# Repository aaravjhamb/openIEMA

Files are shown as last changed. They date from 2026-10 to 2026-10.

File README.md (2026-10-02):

<h1 align="center">OpenIEMA</h1>
<div align="center">

**OpenIEMA** is an Open Source, In Ear Monitor Amplifier built as an alternative to the Behringer P2 with dual headphone outputs driven from a mono balanced XLR input, with onboard LiPo power and USB-C charging!!







</div>

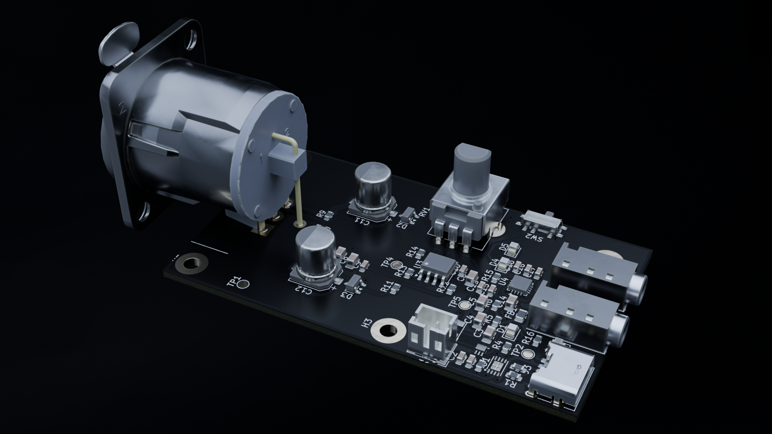
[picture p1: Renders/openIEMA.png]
Hero Render


## Key Features

| | |
|---|---|
| **True balanced input** | Neutrik XLR into an OPA1678 differential line receiver which ensures any long cable runs from the mixer stay noise free |
| **Dual 3.5mm outputs** | supports up to two IEM users off one beltpack, driven by a TI TPA6132A2 DirectPath amp! |
| **Analog soft limiter** | anti parallel LEDs act as soft limiters that clamp excess noise before you hear it! |
| **Fully portable** | Uses a 1S LiPo with USB C charging (MCP73831, 500 mA) and a boost converter to a clean 5 V analog rail, charges while switched off |
| **Zero firmware** | 100% analog signal path built for simplicity |
| **3D-printed enclosure** | Includes a 3D printed enclosure with volume control all in a compact package! |

## PCB

40 × 70 mm, 2-layer, designed in KiCad 10.

**Schematic:**

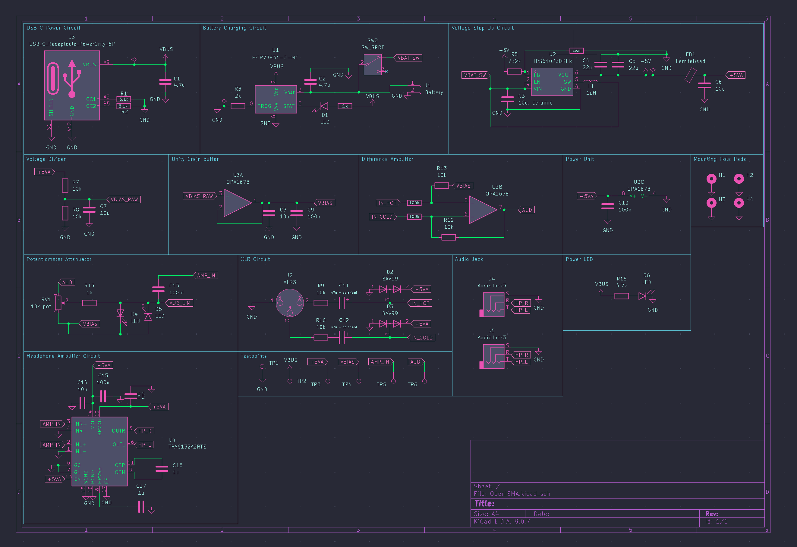
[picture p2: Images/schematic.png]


**Layout:**

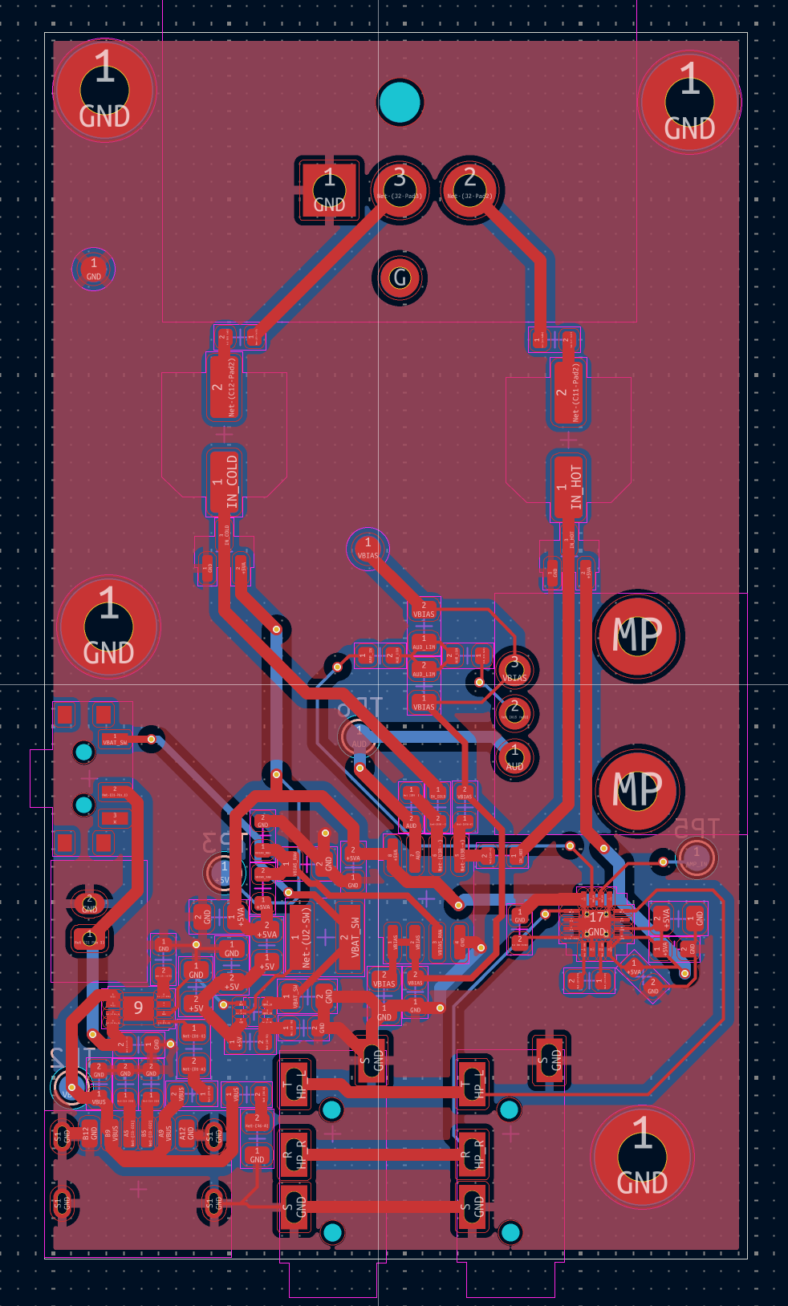
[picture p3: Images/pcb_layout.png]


**3D View:**

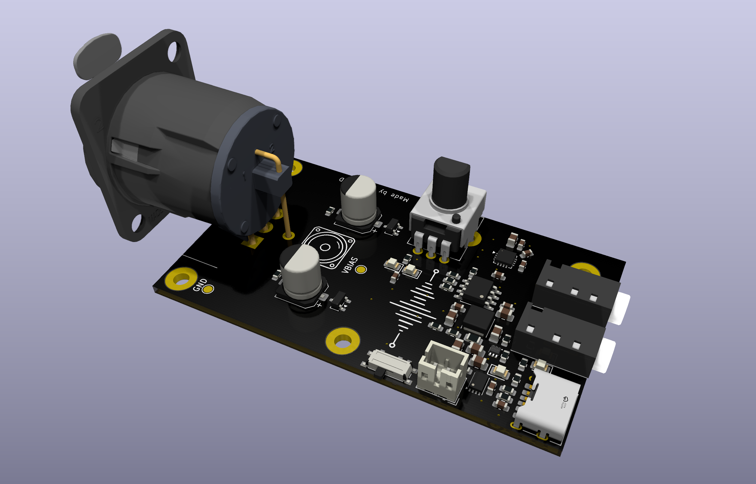
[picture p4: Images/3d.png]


## Case

Designed in Fusion 360

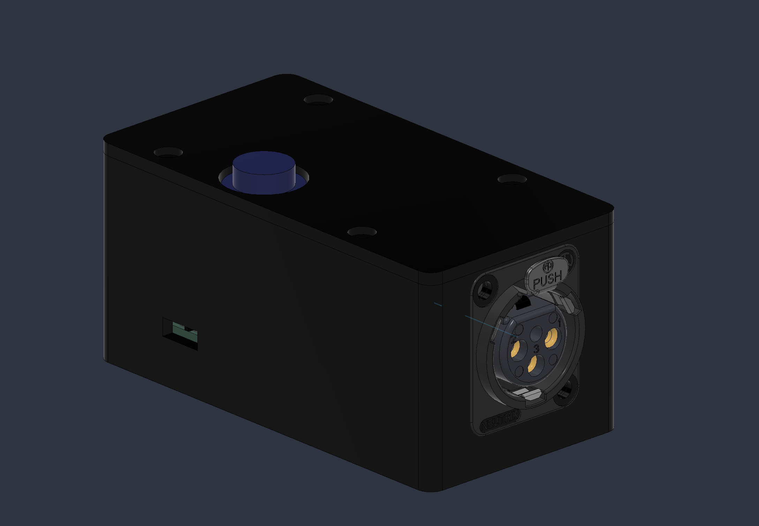
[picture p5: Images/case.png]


## Credits

This project uses:

- [KiCad 10](https://www.kicad.org/) for schematic capture and layout
- [pcb2blender](https://github.com/30350n/pcb2blender) for the Blender renders
- TI TPA6132A2 + OPA1678, Microchip MCP73831, TI TPS61023

## License

MIT

---

> [aaravj.tech]() · GitHub [@aaravjhamb](https://github.com/aaravjhamb/)

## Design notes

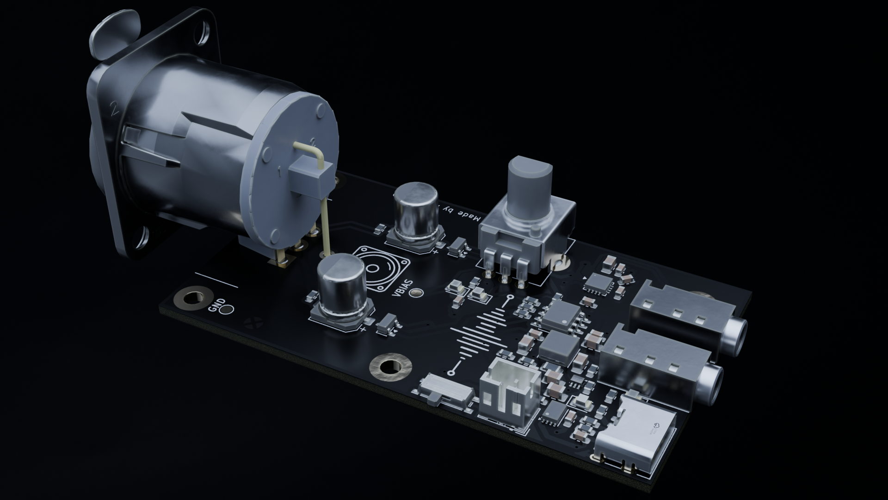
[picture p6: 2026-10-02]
Images/openIEMA.png

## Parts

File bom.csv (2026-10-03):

Designator | Qty | Value / Part | Description | Footprint / Package | LCSC Part # | Source | Cost (AUD)
C1, C2 | 2 | 4.7u |  | 0603 |  | JLCPCB
C10, C15, C16, C9 | 4 | 100n |  | 0603 |  | JLCPCB
C11, C12 | 2 | 47u - polarized |  | CP_Elec_6.3x7.7 |  | JLCPCB
C13 | 1 | 100nf |  | 0603 |  | JLCPCB
C14, C6, C7, C8 | 4 | 10u |  | 0805 |  | JLCPCB
C17, C18 | 2 | 1u |  | 0603 |  | JLCPCB
C3 | 1 | 10u, ceramic |  | 0805 |  | JLCPCB
C4, C5 | 2 | 22u |  | 0805 |  | JLCPCB
D1, D4, D5, D6 | 4 | LED |  | 0805 |  | JLCPCB
D2, D3 | 2 | BAV99 |  | SOT-23 |  | JLCPCB
FB1 | 1 | FerriteBead |  | 0805 |  | JLCPCB
J1 | 1 | Battery |  | JST_PH_B2B-PH-K_1x02_P2.00mm_Vertical |  | JLCPCB
J2 | 1 | XLR3 |  | Jack_XLR_Neutrik_NC3FD-H_Horizontal |  | JLCPCB
J3 | 1 | USB_C_Receptacle_PowerOnly_6P |  | USB_C_Receptacle_HRO_TYPE-C-31-M-17 |  | JLCPCB
J4, J5 | 2 | AudioJack3 |  | Jack_3.5mm_PJ320A_Horizontal | C12569 | JLCPCB
L1 | 1 | 1uH |  | L_Taiyo-Yuden_NR-40xx |  | JLCPCB
R1, R2 | 2 | 5.1k |  | 0603 |  | JLCPCB
R10, R12, R13, R7, R8, R9 | 6 | 10k |  | 0603 |  | JLCPCB
R11, R14, R6 | 3 | 100k |  | 0603 |  | JLCPCB
R15, R4 | 2 | 1k |  | 0603 |  | JLCPCB
R16 | 1 | 4.7k |  | 0603 |  | JLCPCB
R3 | 1 | 2k |  | 0603 |  | JLCPCB
R5 | 1 | 732k |  | 0603 |  | JLCPCB
RV1 | 1 | 10k pot |  | Potentiometer_Bourns_PTV09A_Single_Vertical |  | JLCPCB
SW2 | 1 | SW_SPDT |  | SW_SPDT_PCM12 |  | JLCPCB
TP1, TP2, TP3, TP4, TP5, TP6 | 6 | TestPoint |  | TestPoint_Pad_D1.5mm |  | JLCPCB
U1 | 1 | MCP73831-2-MC |  | DFN-8-1EP_3x2mm_P0.5mm_EP1.7x1.4mm |  | JLCPCB
U2 | 1 | TPS61023DRLR |  | SOT-563_L1.6-W1.2-P0.50-LS1.6-BR | C919459 | JLCPCB
U3 | 1 | OPA1678 |  | SOIC-8_3.9x4.9mm_P1.27mm |  | JLCPCB
U4 | 1 | TPA6132A2RTE |  | WQFN-16-1EP_3x3mm_P0.5mm_EP1.6x1.6mm_ThermalVias |  | JLCPCB
 | 1 | Silk PLA | Case |  |  | Jaycar | $19
 | 1 | IEM | In ear monitors for testing |  |  | https://www.amazon.com.au/KS1-Headphones-Resolution-Detachable-Black-Nomic/dp/B08TWQ3TR7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 | $25
 | 1 | Polymer Lithium Ion Battery (LiPo) 3.7V 1100mAh | Battery |  |  | https://core-electronics.com.au/polymer-lithium-ion-battery-1000mah-38458.html | $9
 |  |  |  |  |  | Non-PCB subtotal | $53

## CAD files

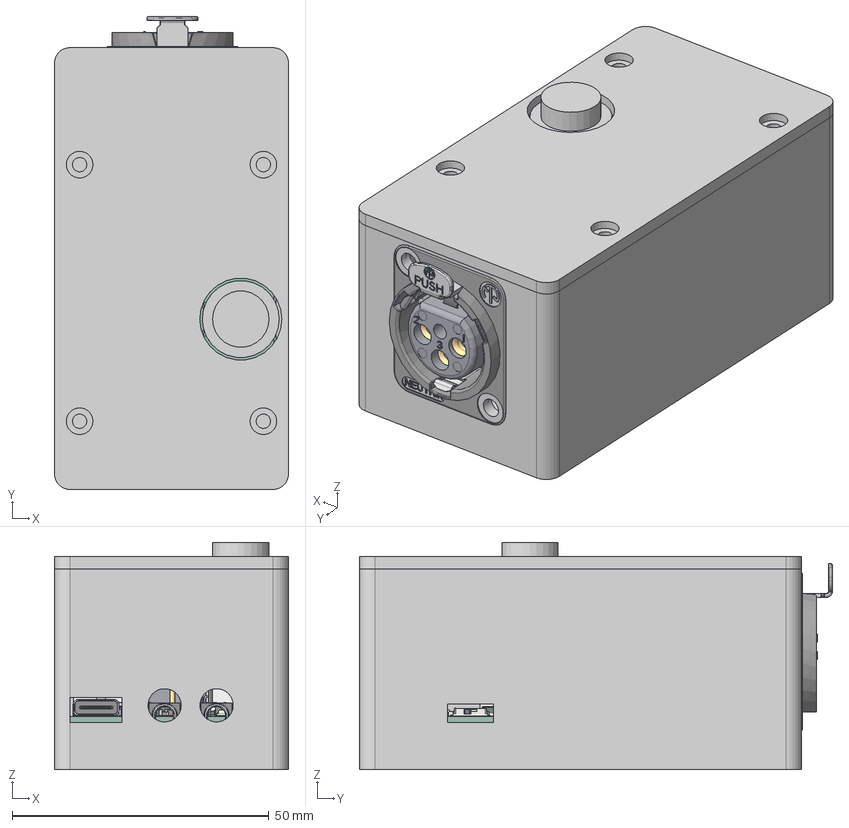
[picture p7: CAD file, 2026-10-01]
CAD/STEPS/OpenIEMA Assembly.step
45.6 x 92.2 x 44.3 mm
C_0603_1608Metric x 9
Potentiometer_Bourns_PTV09A_Single_Vertical
C_0805_2012Metric x 7
LED_0805_2012Metric x 4
AUDIO-TH_PJ-320A x 2
CP_Elec_6.3x7.7 x 2
SOT-23 x 2
JST_PH_B2B-PH-K_1x02_P2.00mm_Vertical
DFN-8-1EP_3x2mm_P0.5mm_EP1.75x1.45mm
SOIC-8_3.9x4.9mm_P1.27mm
R_0603_1608Metric x 16
SOT-563-6P_L1.6-W1.2-H0.6-LS1.6-P0.50
WQFN-16-1EP_3x3mm_P0.5mm_EP1.6x1.6mm
SW_SPDT_PCM12
USB_C_Receptacle_HRO_TYPE-C-31-M-17
L_APV_ANR4018
R_0805_2012Metric
OpenIEMA_PCB
OpenIEMA Case

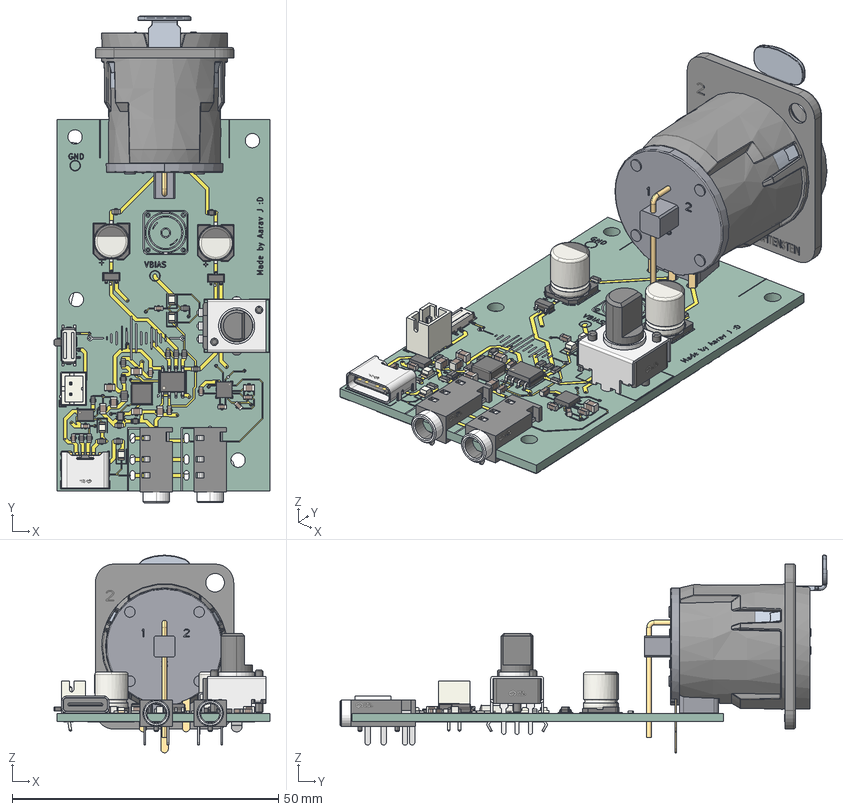
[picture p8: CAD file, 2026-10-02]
CAD/STEPS/OpenIEMA.step
40.6 x 91.4 x 37.1 mm
C_0603_1608Metric x 9
Potentiometer_Bourns_PTV09A_Single_Vertical
C_0805_2012Metric x 7
LED_0805_2012Metric x 4
AUDIO-TH_PJ-320A x 2
CP_Elec_6.3x7.7 x 2
SOT-23 x 2
JST_PH_B2B-PH-K_1x02_P2.00mm_Vertical
DFN-8-1EP_3x2mm_P0.5mm_EP1.75x1.45mm
SOIC-8_3.9x4.9mm_P1.27mm
R_0603_1608Metric x 16
SOT-563-6P_L1.6-W1.2-H0.6-LS1.6-P0.50
WQFN-16-1EP_3x3mm_P0.5mm_EP1.6x1.6mm
SW_SPDT_PCM12
USB_C_Receptacle_HRO_TYPE-C-31-M-17
L_APV_ANR4018
R_0805_2012Metric
OpenIEMA_copper
OpenIEMA_via
OpenIEMA_silkscreen x 2
OpenIEMA_PCB

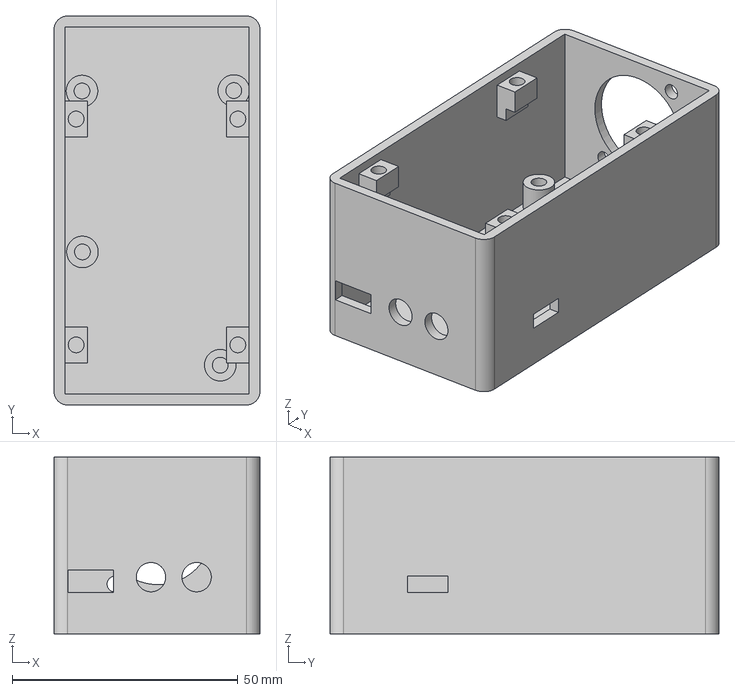
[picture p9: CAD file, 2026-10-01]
CAD/STEPS/Base.step
45.6 x 86.1 x 39.1 mm

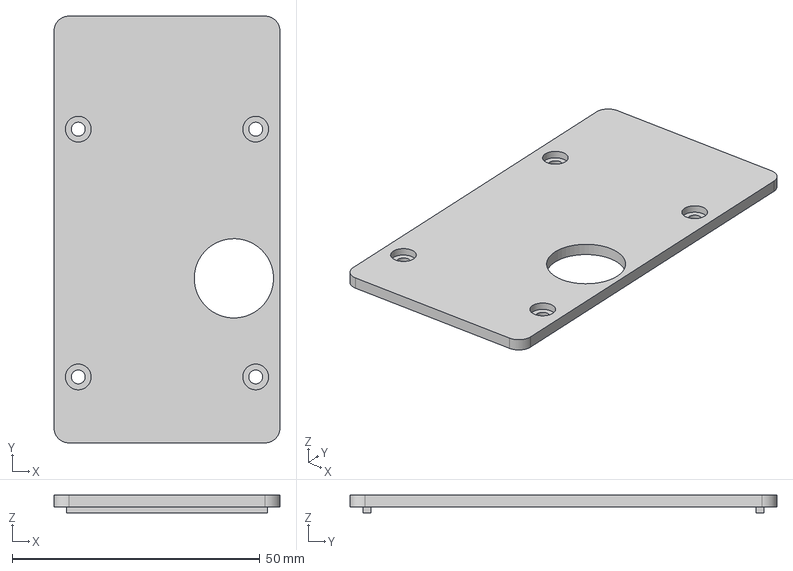
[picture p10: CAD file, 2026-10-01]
CAD/STEPS/Lid.step
45.6 x 86.1 x 3.60 mm

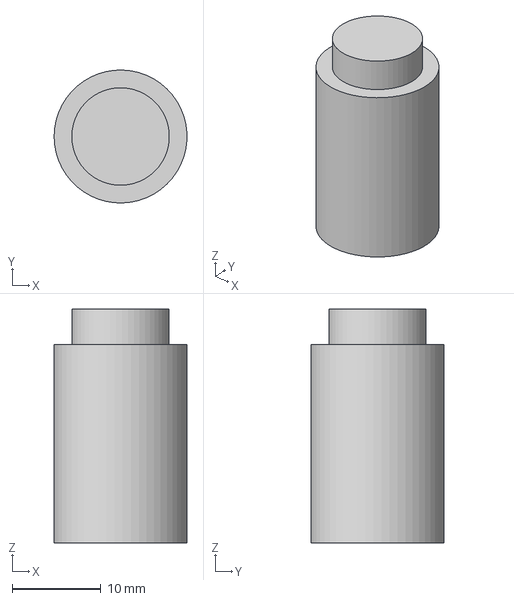
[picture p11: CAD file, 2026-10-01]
CAD/STEPS/Knob.step
15.0 x 15.0 x 26.4 mm

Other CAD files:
CAD/3D Printing/Base.stl
CAD/3D Printing/Knob.stl
CAD/3D Printing/Lid.stl
Renders/openIEMA.blend

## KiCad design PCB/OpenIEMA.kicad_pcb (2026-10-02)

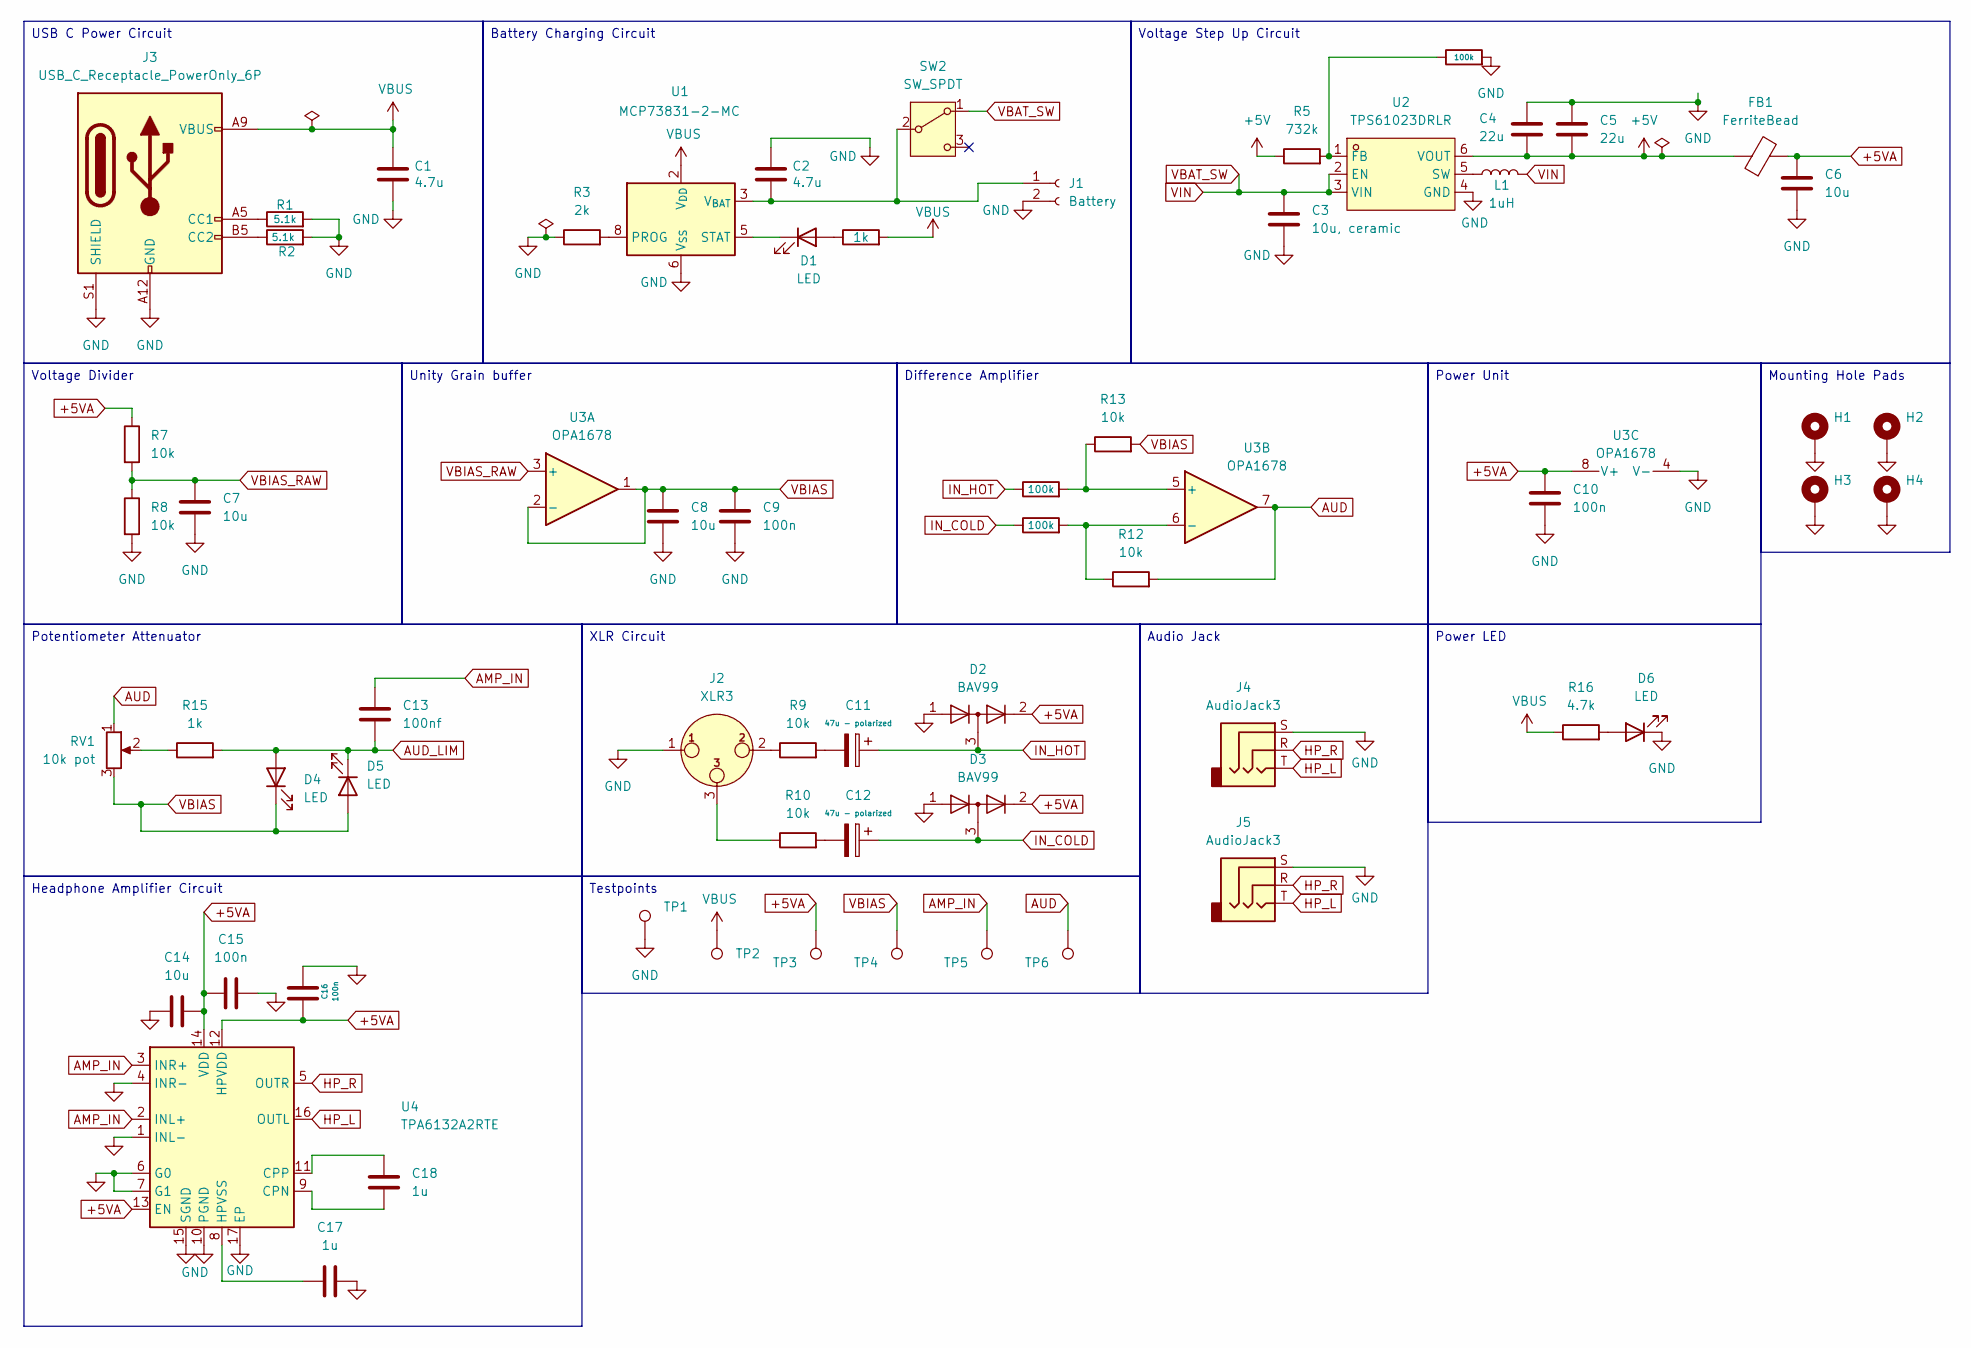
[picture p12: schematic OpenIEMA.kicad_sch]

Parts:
C1, C2: 4.7u; C_0603_1608Metric
C3: 10u, ceramic; C_0805_2012Metric
C4, C5: 22u; C_0805_2012Metric
C6, C7, C8, C14: 10u; C_0805_2012Metric
C9, C10, C15, C16: 100n; C_0603_1608Metric
C11, C12: 47u - polarized; CP_Elec_6.3x7.7
C13: 100nf; C_0603_1608Metric
C17, C18: 1u; C_0603_1608Metric
D1, D4, D5, D6: LED; LED_0805_2012Metric
D2, D3: BAV99; SOT-23
FB1: FerriteBead; R_0805_2012Metric
H1, H2, H3, H4: MountingHole_Pad; MountingHole_2.7mm_M2.5_Pad
J1: Battery; JST_PH_B2B-PH-K_1x02_P2.00mm_Vertical
J2: XLR3; Jack_XLR_Neutrik_NC3FD-H_Horizontal
J3: USB_C_Receptacle_PowerOnly_6P; USB_C_Receptacle_HRO_TYPE-C-31-M-17
J4, J5: AudioJack3; Jack_3.5mm_PJ320A_Horizontal
L1: 1uH; L_Taiyo-Yuden_NR-40xx
R1, R2: 5.1k; R_0603_1608Metric
R3: 2k; R_0603_1608Metric
R4, R15: 1k; R_0603_1608Metric
R5: 732k; R_0603_1608Metric
R6, R11, R14: 100k; R_0603_1608Metric
R7, R8, R9, R10, R12, R13: 10k; R_0603_1608Metric
R16: 4.7k; R_0603_1608Metric
RV1: 10k pot; Potentiometer_Bourns_PTV09A_Single_Vertical
SW2: SW_SPDT; SW_SPDT_PCM12
TP1, TP2, TP3, TP4, TP5, TP6: TestPoint; TestPoint_Pad_D1.5mm
U1: MCP73831-2-MC; DFN-8-1EP_3x2mm_P0.5mm_EP1.7x1.4mm
U2: TPS61023DRLR; SOT-563_L1.6-W1.2-P0.50-LS1.6-BR; MPN TPS61023DRLR; LCSC Part C919459
U3: OPA1678; SOIC-8_3.9x4.9mm_P1.27mm
U4: TPA6132A2RTE; WQFN-16-1EP_3x3mm_P0.5mm_EP1.6x1.6mm_ThermalVias

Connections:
+5V: C4.2, C5.2, FB1.1, R5.1, U2.6 (VOUT)
+5VA: C6.1, C10.2, C14.2, C15.1, C16.1, D2.2 (A), D3.2 (A), FB1.2, R7.1, TP3.1, U3.8 (V+), U4.12 (HPVDD), U4.13 (EN), U4.14 (VDD)
AMP_IN: C13.1, TP5.1, U4.2 (INL+), U4.3 (INR+)
AUD: R12.2, RV1.1, TP6.1, U3.7
AUD_LIM: C13.2, D4.2 (A), D5.1 (K), R15.2
GND: C1.2, C2.1, C3.2, C4.1, C5.1, C6.2, C7.2, C8.1, C9.1, C10.1, C14.1, C15.2, C16.2, C17.1, D2.1 (K), D3.1 (K), D6.1 (K), H1.1, H2.1, H3.1, H4.1, J1.2, J2.1, J3.A12 (GND), J3.B12 (GND), J3.S1 (SHIELD), J4.S, J5.S, R1.2, R2.2, R3.1, R6.2, R8.2, TP1.1, U1.6 (V_{SS}), U2.4 (GND), U3.4 (V-), U4.1 (INL-), U4.4 (INR-), U4.6 (G0), U4.7 (G1), U4.10 (PGND), U4.15 (SGND), U4.17 (EP)
HP_L: J4.T, J5.T, U4.16 (OUTL)
HP_R: J4.R, J5.R, U4.5 (OUTR)
IN_COLD: C12.1, D3.3 (K), R11.1
IN_HOT: C11.1, D2.3 (K), R14.1
unnamed: C11.2, R9.2
unnamed: C12.2, R10.2
unnamed: D1.2 (A), R4.1
unnamed: D1.1 (K), U1.5 (STAT)
unnamed: D6.2 (A), R16.2
unnamed: C2.2, J1.1, SW2.2 (B), U1.3 (V_{BAT}), U1.4 (V_{BAT})
unnamed: J2.2, R9.1
unnamed: J2.3, R10.1
unnamed: J3.A5 (CC1), R1.1
unnamed: J3.B5 (CC2), R2.1
unnamed: R15.1, RV1.2
unnamed: R3.2, U1.8 (PROG)
unnamed: R5.2, R6.1, U2.1 (FB)
unnamed: L1.1, U2.5 (SW)
unnamed: R13.1, R14.2, U3.5 (+)
unnamed: R11.2, R12.1, U3.6 (-)
unnamed: C18.2, U4.9 (CPN)
unnamed: C18.1, U4.11 (CPP)
unnamed: C17.2, U4.8 (HPVSS)
VBAT_SW: C3.1, L1.2, SW2.1 (A), U2.2 (EN), U2.3 (VIN)
VBIAS: C8.2, C9.2, D4.1 (K), D5.2 (A), R13.2, RV1.3, TP4.1, U3.1, U3.2 (-)
VBIAS_RAW: C7.1, R7.2, R8.1, U3.3 (+)
VBUS: C1.1, J3.A9 (VBUS), J3.B9 (VBUS), R4.2, R16.1, TP2.1, U1.1 (V_{DD}), U1.2 (V_{DD})

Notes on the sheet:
Potentiometer Attenuator
Testpoints
Mounting Hole Pads
Voltage Step Up Circuit
Voltage Divider
Battery Charging Circuit
Audio Jack
Headphone Amplifier Circuit
Power LED
USB C Power Circuit
Power Unit
Difference Amplifier
Unity Grain buffer
XLR Circuit

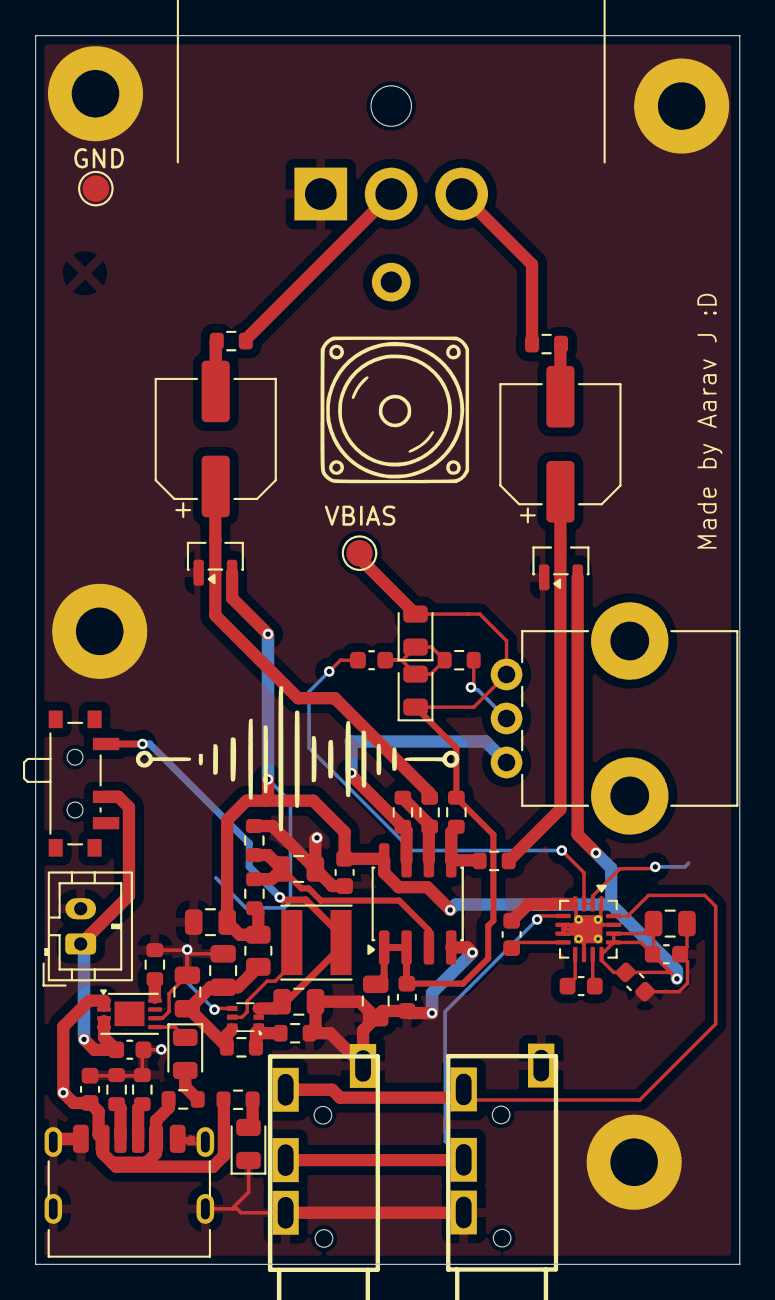
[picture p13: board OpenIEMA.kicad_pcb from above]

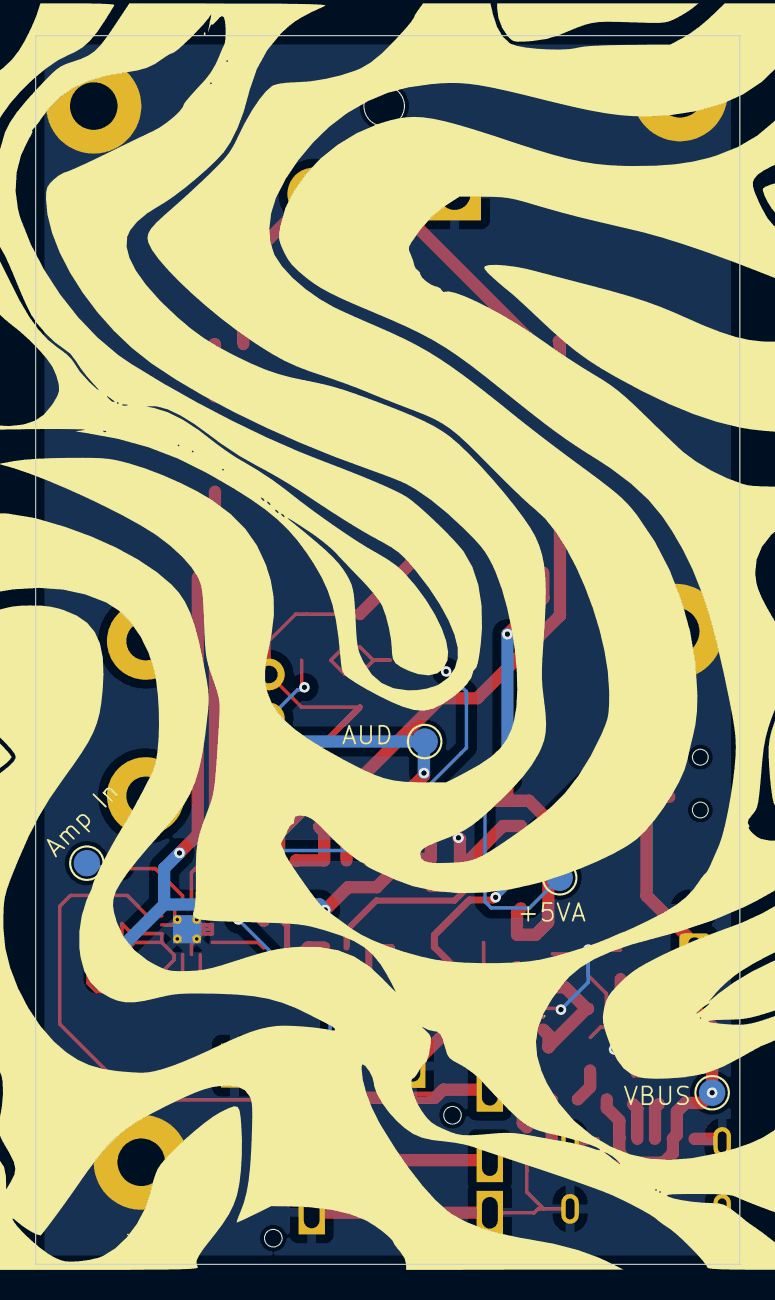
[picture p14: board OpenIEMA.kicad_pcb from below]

Board: 2 copper layers, 40.0 x 69.8 mm, 63 parts (4 on the bottom side), 33 nets.

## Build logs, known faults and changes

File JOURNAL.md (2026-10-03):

---
title: "openIEMA"
author: "Aarav J"
description: "An Open Source, In Ear Monitor Amplifier built as an alternative to the Behringer P2 with dual headphone outputs driven from a mono balanced XLR input, with onboard LiPo power and USB-C charging!!"
created_at: "2026-10-03"
---

# 2026-10-03: Day 7 - (3/10/26) - Github files + JLC quote

**Total time spent: 1.5 hours**

# Day 7

Quick things today, I did this yesterday but I'm devlogging today

I spent a bit of time organising everything into the right folders and it looked like this



I then wrote my github readme and uploaded all the files to GH with some readme polish!

# Time spent : 1.5 hours

With that the entire project is done :DD total time spent was 

# 2026-10-03: Day 6 (2/10/26) - Blender Renders

**Total time spent: 7 hours**

# Day 6

pcb done!! now It was time to make blender renders :D

To do this I first installed the pcb2blender kicad plugin!


This allows me to take my PCB directly from KiCad and import it into blender using the companion extenion in blender. Once I imported it in blender it looked something like this



I then whent to the shading settings and changed the solder mask colour to black and adjusted the strength aswell as changing the surface finish to enig!


once this was done, I whent down to the world icon and set the environment to studio and downloaded this HDRI pack called "wooden_studio_08_4k" that basically handled the lighting and bg for me!



After that I clicked N and opened the view panel to set my camera view

And then locked the object to camera view so I could recenter the PCB with the camera locked!

Once I recentered I whent into view > align > align camera to current view which allows me to set the current view as the camera's view!



Then I clicked Z and 8 to get a test render



Finally once I was happy with this I clicked render and let it render with this being the final result!



All of this took me quite a while with multiple tries as this is my second time using blender and its certainly a difficult software to understand

Time Spent : 7 hours

# 2026-10-03: Day 5 (2/10/26) - Started PCB

**Total time spent: 6 hours**

# Day 5

To make the PCB I first imported all the components from the schematic



Then I did the PCB layout



I tried to place components as close as possible and ensure that routing wouldn't be too crazy so this took ~3 hours with me redoing the board 3 times. I then added the ground pour on both layers and decided to go with a 2 layer board as 4 layers is overkill imo



Then I spent a bit doing routing


And while doing routing I tried to keep the trace widths and lengths as optimized as possible!

I don't have pictures of my rerouting verions however I do have a 3d model of my old PCB vs new layout!

v1 - 


v2 - 


# Time Spent : 6 hours

# 2026-10-03: Day 4 (1/10/26) - Assigning footprints

**Total time spent: 1.5 hours**

# Day 4

Spent a couple hours assigning footprints, there's not much to say lol





# Time spent : 1.5 hours

# 2026-10-03: Day 3 (30/09/26) - Schematic Continuation

**Total time spent: 9 hours**

# Day 3

more journal shennanigans!!! devlogging for two days

first thing I did today was get started on the voltage divider. this is required as the project has a stable +5v supply coming from +5vA however audio works in the negatives aswqell. Our target is to make the waveform clip at 0v however right now 5/2 is 2.5 so I need to create a voltage divider to allow it to swing betweeen -2.5v and +2.5v

This can be achieved simply by using 2 10k resistors like this



After this I need to design the Unity Gain Buffer. This put simply takes 2.5v in from the  voltage divider and turns it from a weak signal to a stronger signal. This can be achieved using the OPA1678 chip which is a 3 part chip.

Part A (the main part) copies the dividers 2.5v to its output and holds it strong and stable so the rest of the circuit can use it and it looks something like this.



The next part (U3B) uses the same chip btu a different symbol and is called the difference amplifier. This basically takes the 2 XLR signals (hot and cold) and subtracts one from the other to remove cable noise and cleanms the audio to about 20db, this is important if I want to get clear sound and looks something like this



The last and final part of the chip is pretty simple, the chip needs some way to power it and to do that I can use U3C which is the power input of the chip!



It's pretty simple and just takes our cleaned 5va, with a decoupling cap to GND and v- going to ground!

That's the hard part done!! Now I can move onto the fun part's - volume control and sound output but before I move on I actually need to design the XLR input circuit! 



This basically takes the XLR input and shoves it through a diode to prevent backflow and gives the two outputs that then input into the difference amplifier!

Now it's time for the audio volume control! I can achieve this using a potentiometer and 2 LED's that clip the signal such as the high peaks that kill your ears



This also provides accurate volume control going out to the HAC (headphone amplifier circuit) chip



Finally to finish off I added the two headphone jacks,

 and some tespoints and power LED's

once all done, it looked something like this!



Now I can move onto the PCB once I assign footprints

# Time spent : 9 hours

# 2026-10-03: Day 1 - Started Schematic

**Total time spent: 5 hours**

# Day 1

guess who forgot to journal!!! anyway I'm setting out to build an open source IEMA or In Ear Monitor Amplifier for short
I want to build this as an alternative to the Bereginer C2 as that is a bit costly and doesn't have some features I want

To get started I'm going to be making this project as a fully analog circuit!! since this is my first time I'm going to have to understand how sound engineering works(fun)

my first step was to add USB C with the usual setup like so



This is just a simple USB C PCB implementation that has 2 5.1k resistors to invoke the USB C power protocol + a power flag so kicad stops yelling at me and a simple decoupling cap placed on vbus for stability!

The next step was to add a battery charging circuit and do some research for the chip + the battery capacity and time I wanted the device to operate. My first thoughts was to use the TP4056 charging module but I wanted to go with something new and easier and more efficient to operate so after consulting my [boss] claude I decided to go with the MCP73831-2-MC chip. 

I then whent throughout the [datasheet](https://ww1.microchip.com/downloads/en/DeviceDoc/MCP73831-Family-Data-Sheet-DS20001984H.pdf) and tried to find an example circuit that looked somethinig like this



I imported it into kicad and made a circuit that looked something similar to this



This circuit is pretty simple and in essence here's what the pins do

#### Pin 8
 - Programming pin for charging speed, putting a 2k resistor charges the battery at 500mah for a 1k cell
#### Pin 6
  - ground :D
#### Pin 2
- +5v Power
#### Pin 3
- Battery input/output basically where the chip will charge and send power to the battery
#### Pin 5
 - Status LED for when the battery is charging!

Overall pretty simple so time to move on.

The next step was to implement a battery boost converter considering our battery will only be sending ~3.7v on a full charge and ~3v when it's empty however our circuit needs a steady 5v with no fluctuatioins and noise

To do this I'm going to use the TPS61023DRLR chip as a step up voltage circuit implemented like so



This circuit is a combination of capacitors for decoupling and a ferrite bead to get a clean and desnoised +5vA input that will be used for the soujnd circuitry later on.

with that I'm going to finish today's devlog as I'll work on the rest tommorow!

# Time spent : 5h

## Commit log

2026-10-01 Add files via upload?
    [Base.step, Base.stl, Knob.step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]
2026-10-01 Add case ikmage
2026-10-02 New PCB layout and routing + schematic cleanup
    [OpenIEMA.kicad_pcb, OpenIEMA.kicad_sch]
2026-10-02 New steps + silkscreen
    [OpenIEMA.kicad_pcb, OpenIEMA.step]
2026-10-02 Remove old renders and add new ones
    [openIEM.blend, openIEMA.blend]
2026-11-02 v2 PCB files!!
